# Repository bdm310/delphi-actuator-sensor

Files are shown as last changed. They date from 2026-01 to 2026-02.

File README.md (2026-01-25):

# delphi-actuator-sensor
Replacement position sensor PCB for VAG/Porsche/Delphi HVAC actuators commonly used on the Porsche 955/9PA Cayenne, VW 7L Touareg, and perhaps Audi Q7. The original Alps resistive sensor usually fouls due to excessive grease application from the factory and appears to be a custom 4.7kOhm, 120 degree part that isn't purchasable. The closest sensor is the RDC503052A in the same mechanical package but it does not match the original electrical angle. This project matches the output of that sensor to the original range.

The connector pin spacing is 2.85mm and the pin headers used here are 2.54mm. Suggest soldering these on yourself as they need to be flush with the board and you can then tweak them as necessary to fit in the existing housing.

Non-comprehensive list of potentially applicable part numbers:
 - 955 624 901 01
 - 955 624 905 01
 - 955 624 902 01
 - 955 624 908 01
 - 955 624 909 01
 - 955 624 913 01
 - 955 624 912 01
 - 7L0907511AK (supersedes 7L0907511D)
 - 7L0907511AL (supersedes 7L0907511E)
 - 7L0907512G
 - 7L0907512F (supersedes 7L0907512)
 - 7L0907511AB
 - 7L0907511AD 

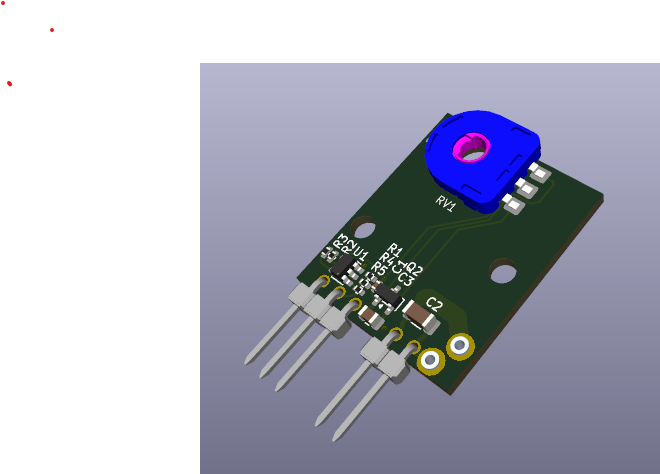
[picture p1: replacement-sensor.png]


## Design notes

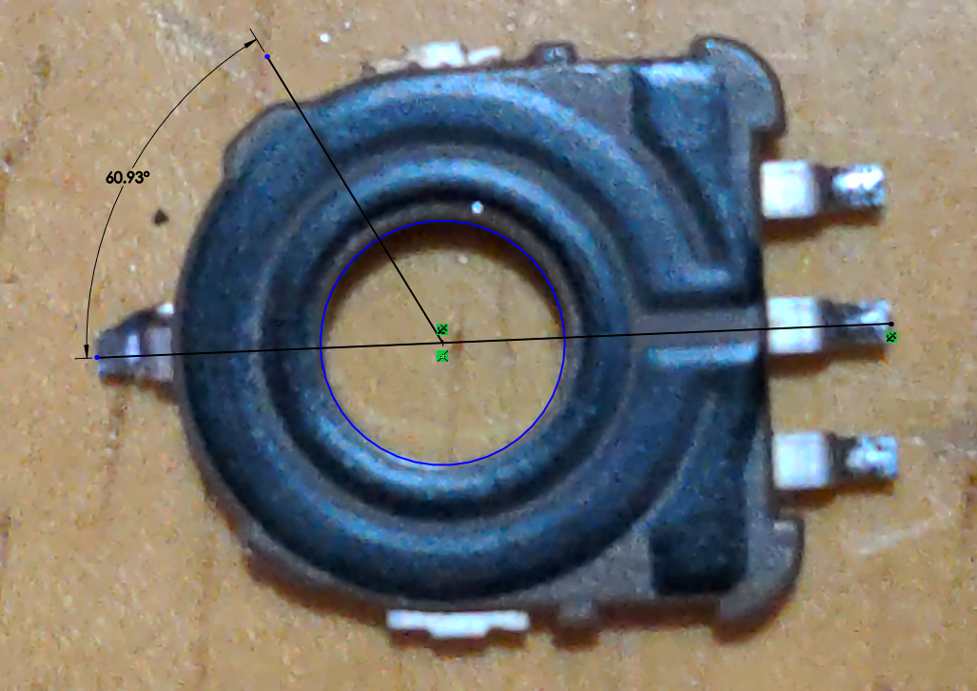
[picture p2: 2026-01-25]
original-sensor-range.png

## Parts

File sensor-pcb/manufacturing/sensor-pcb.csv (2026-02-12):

Reference | Qty | Value | Comment
C1 | 1 | 1u | GCM155C71A105KE38D
C2 | 1 | 470n | CGA5L2X7R1H474K160AA
C3 | 1 | 10u | GRM21BR61H106KE43L
J1 | 1 | Conn_01x03 | 22289031
J2 | 1 | Conn_01x02 | 22288021
J3,J4 | 2 | Conn_01x01_Socket | 0666-0-15-15-32-27-10-0
Q7 | 1 | BSS84DW-7-F | BSS84DW-7-F
Q8 | 1 | 2N7002DW | 2N7002DW
R1 | 1 | 10k | RMCF0402FT10K0
R2,R3 | 2 | 11k5 | RMCF0402FT11K5
R4 | 1 | 100k | RMCF0402FT100K
R5 | 1 | 2k2 | RMCF0402FT2K20
RV1 | 1 | RDC503052A | RDC503052A
U1 | 1 | TLV9151IDBVR | TLV9151IDBVR

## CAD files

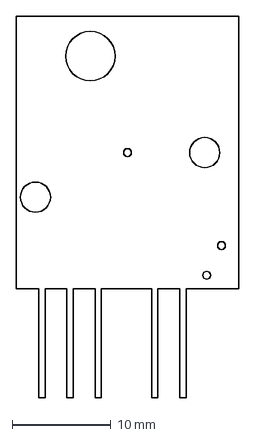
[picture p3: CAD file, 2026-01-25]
original-board.DXF
22.5 x 38.5 mm

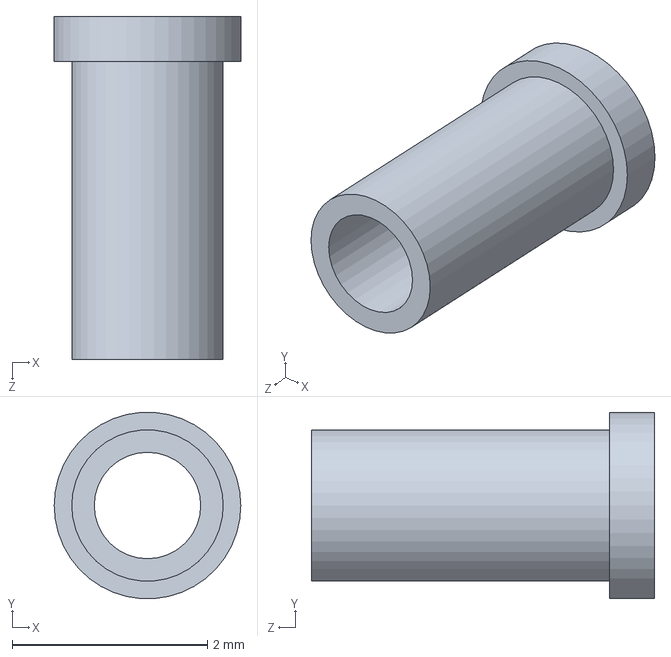
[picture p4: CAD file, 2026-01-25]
0666-0-15-15-32-27-10-0.SLDPRT
1.91 x 1.90 x 3.51 mm

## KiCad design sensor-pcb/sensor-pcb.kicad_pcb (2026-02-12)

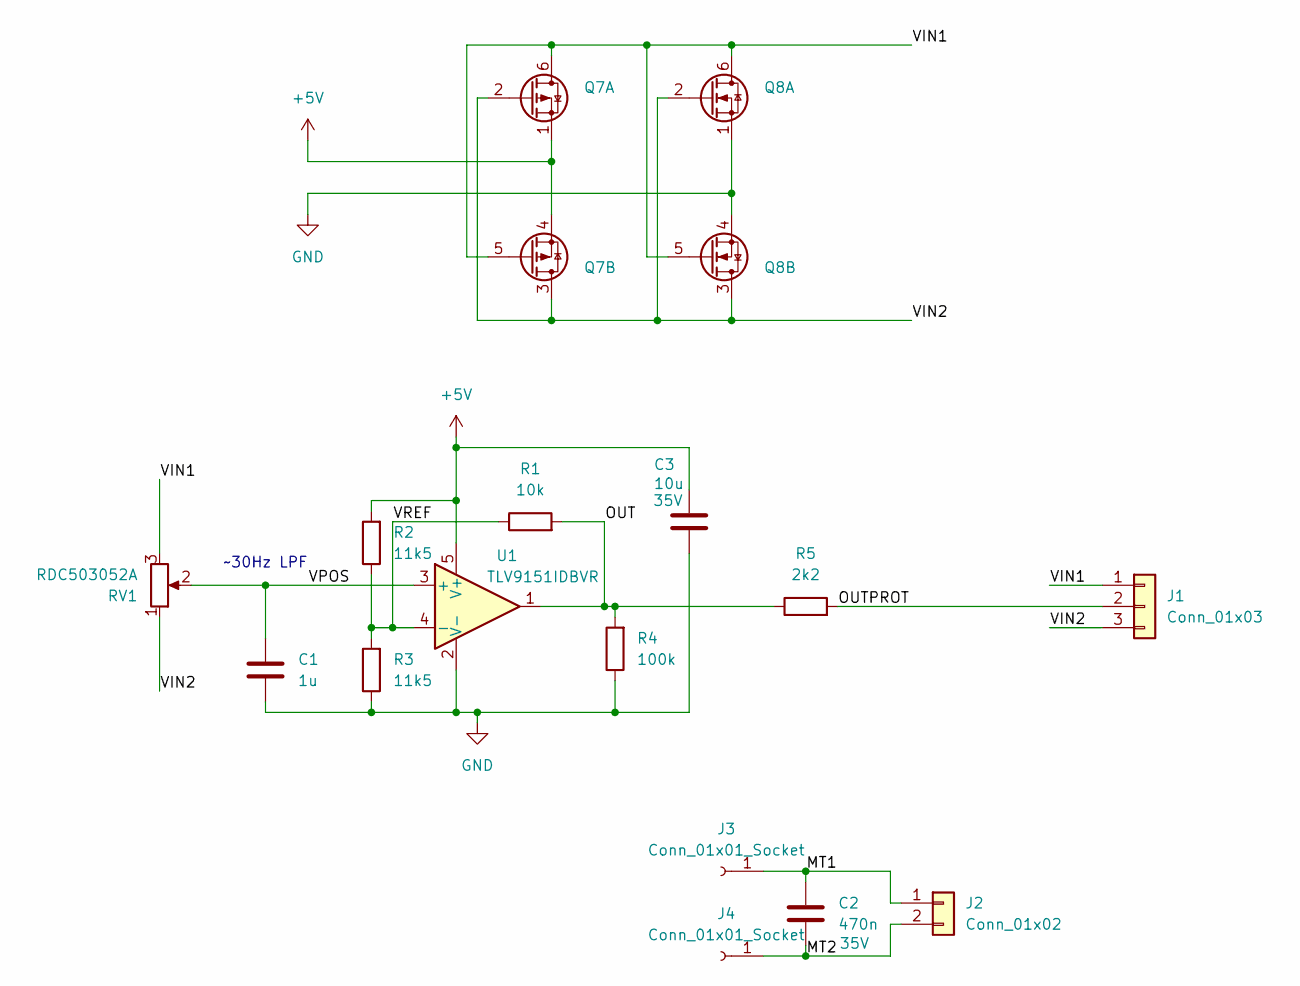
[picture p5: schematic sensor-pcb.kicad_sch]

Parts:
C1: 1u; C_0402_1005Metric; MPN GCM155C71A105KE38D
C2: 470n; C_1206_3216Metric; Voltage Rating 35V; MPN CGA5L2X7R1H474K160AA
C3: 10u; C_0805_2012Metric; Voltage Rating 35V; MPN GRM21BR61H106KE43L
J1: Conn_01x03; CONN03_22289031_MOL; MPN 22289031
J2: Conn_01x02; CONN02_22288021_MOL; MPN 22288021
J3, J4: Conn_01x01_Socket; 0666-0-15-15-32-27-10-0; MPN 0666-0-15-15-32-27-10-0
Q7: BSS84DW-7-F; SOT-363_SC-70-6; MPN BSS84DW-7-F
Q8: 2N7002DW; SOT-363_SC-70-6; MPN 2N7002DW
R1: 10k; R_0402_1005Metric; MPN RMCF0402FT10K0
R2, R3: 11k5; R_0402_1005Metric; MPN RMCF0402FT11K5
R4: 100k; R_0402_1005Metric; MPN RMCF0402FT100K
R5: 2k2; R_0402_1005Metric; MPN RMCF0402FT2K20
RV1: RDC503052A; alps-rcd50-smd; MPN RDC503052A
U1: TLV9151IDBVR; SOT-23-5; MPN TLV9151IDBVR

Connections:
+5V: C3.1, Q7.1 (S), Q7.4 (S), R2.2, U1.5 (V+)
/MT1: C2.1, J2.1, J3.1
/MT2: C2.2, J2.2, J4.1
/OUT: R1.2, R4.2, R5.1, U1.1
/OUTPROT: J1.2, R5.2
/VIN1: J1.1, Q7.5 (G), Q7.6 (D), Q8.5 (G), Q8.6 (D), RV1.3
/VIN2: J1.3, Q7.2 (G), Q7.3 (D), Q8.2 (G), Q8.3 (D), RV1.1
/VPOS: C1.1, RV1.2, U1.3 (+)
/VREF: R1.1, R2.1, R3.2, U1.4 (-)
GND: C1.2, C3.2, Q8.1 (S), Q8.4 (S), R3.1, R4.1, U1.2 (V-)

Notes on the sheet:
~30Hz LPF

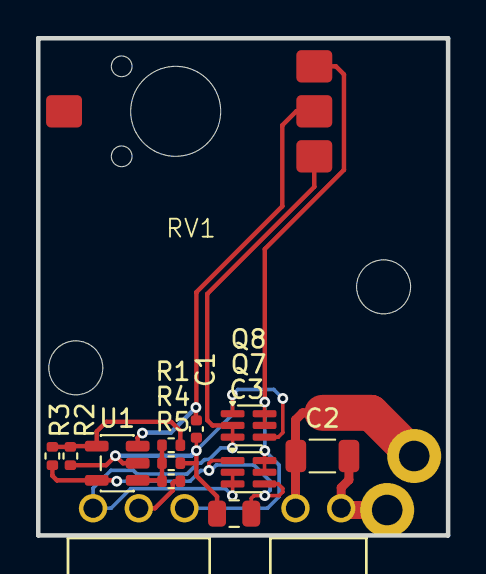
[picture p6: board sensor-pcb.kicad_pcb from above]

Board: 2 copper layers, 22.8 x 27.6 mm, 19 parts (0 on the bottom side), 10 nets.

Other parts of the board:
MH1: MountingHole_5mm
MH2, MH3: MountingHole_3mm

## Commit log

2026-01-25 Add board image
2026-02-11 Fix flipped power pins
    [sensor-pcb-B_Cu.gbr, sensor-pcb-B_Mask.gbr, sensor-pcb-B_Paste.gbr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]
2026-02-11 Reverse direction
    [sensor-pcb-B_Cu.gbr, sensor-pcb-B_Mask.gbr, sensor-pcb-B_Paste.gbr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]
2026-02-12 Change design to allow arbitrary polarity
    [sensor-pcb-B_Cu.gbr, sensor-pcb-B_Mask.gbr, sensor-pcb-B_Paste.gbr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]
